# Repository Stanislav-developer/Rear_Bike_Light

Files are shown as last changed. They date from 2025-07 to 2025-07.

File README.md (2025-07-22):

# __Rear_Bike_Light__







## __DIY велоліхтарик__ 🚲 🔦
### Простий та функціональний задній ліхтарик для велосипеда на базі мікроконтролера ATtiny13. Ліхтарик має різні режими світіння, функцію пам’яті режимів та енергозбереження, стабілізацію яскравості і працює від Li-Ion акумулятора
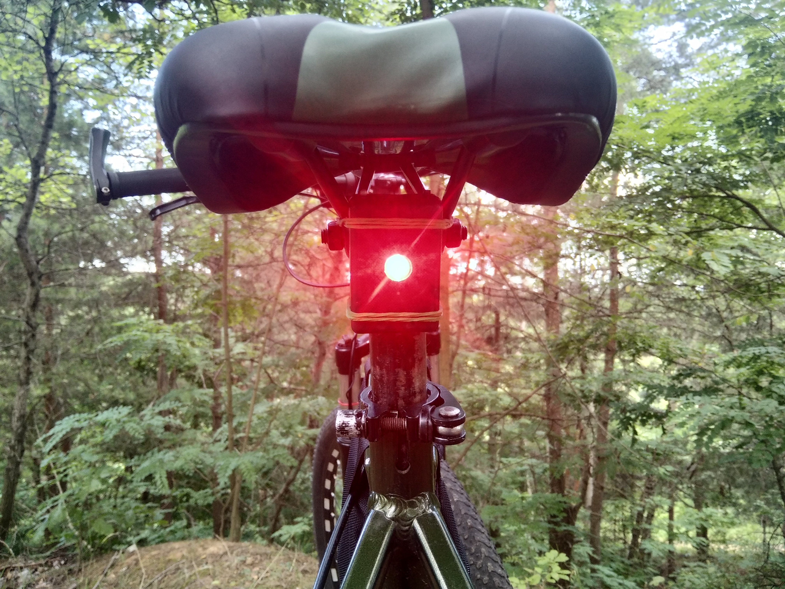
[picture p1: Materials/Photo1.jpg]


### 📹 [Відеодемонстрація роботи](https://youtu.be/wDcFlRhbskA)

### 📹 [Огляд на YouTube](https://youtu.be/hUzTWR3Yd6k?si=01EYvAU8pgUhFRcD)
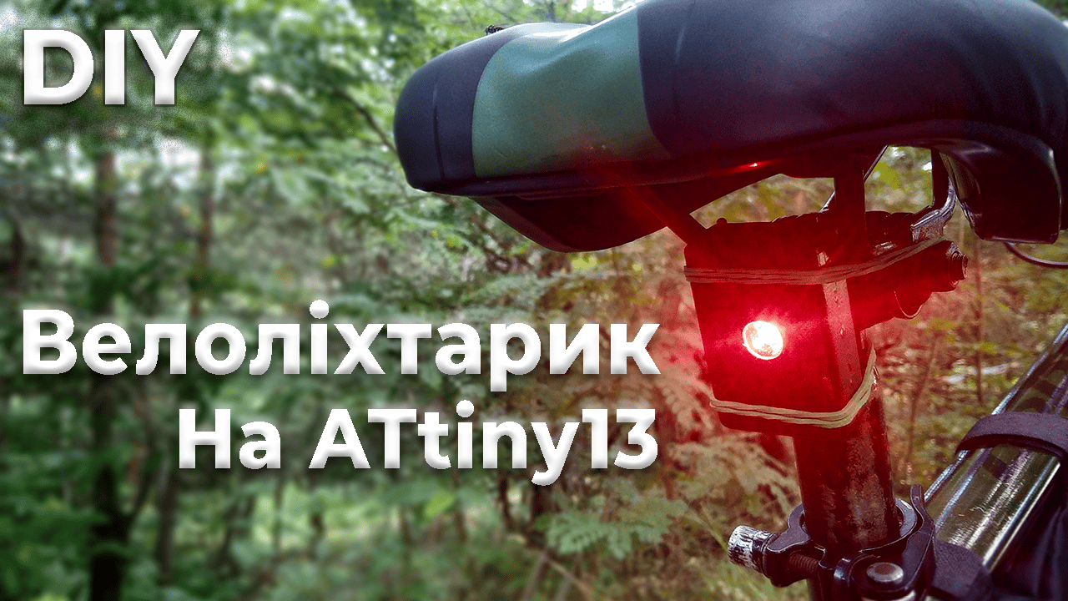
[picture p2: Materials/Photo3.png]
(https://youtu.be/hUzTWR3Yd6k)


## 📝 Можливості ліхтарика
- ### Керування однією кнопкою (довге/коротке натискання)
- ### Режими світіння: 3 рівня яскравості, миготіння, дихаючий режим, еко-режим
- ### Запам’ятовує останній режим (енергонезалежна EEPROM пам’ять)
- ### Стабілізована яскравість (AMC7135)
- ### Дуже низьке споживання енергії в режимі сну (~20 мкА)

## Схема ліхтарика:
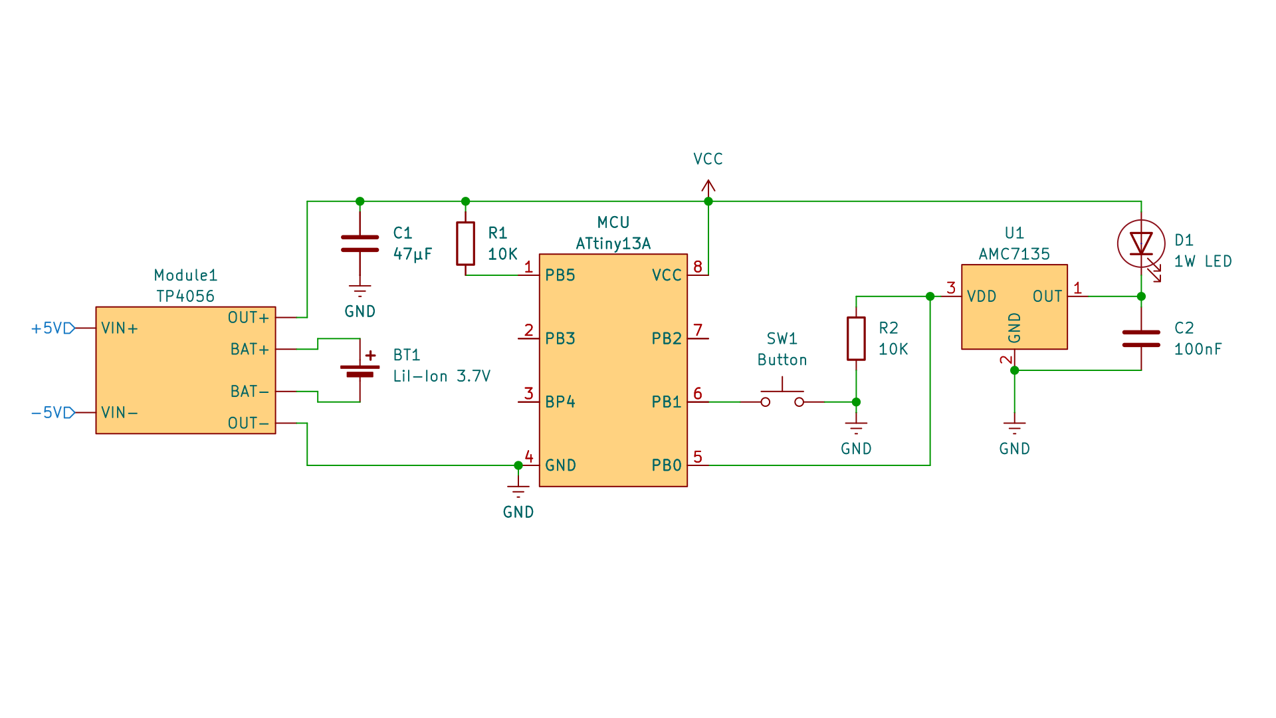
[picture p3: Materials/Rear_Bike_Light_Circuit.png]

### Перелік компонентів, інструкція з пайки та схема розміщені у [PDF документації](https://github.com/Stanislav-developer/Rear_Bike_Light/blob/main/Rear_Bike_Light.pdf)

## 📑 [PDF документ](https://github.com/Stanislav-developer/Rear_Bike_Light/blob/main/Rear_Bike_Light.pdf) у якому описав весь функціонал, збірку та прошивку ліхтарика.

### Поточна версія проекту: 1.0

### [Мій YouTube](https://www.youtube.com/@TehnoMaisterna)
### [Мій GitHub](https://github.com/Stanislav-developer)

### 2025.07.20

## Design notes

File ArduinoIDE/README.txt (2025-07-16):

Спершу встановіть ядро для роботи з ATtiny13:

Установка ядра MicroCore в Arduino IDE
Для роботи MicroCore потрібна версія Arduino IDE не нижче 1.6.13.
Інструкція з встановлення:

1.Відкрийте Arduino IDE.

2.Перейдіть у меню Файл → Налаштування.

3.У поле Додаткові URL-адреси менеджера плат вставте наступне посилання:

https://mcudude.github.io/MicroCore/package_MCUdude_MicroCore_index.json

4.Відкрийте меню Інструменти → Плата → Менеджер плат...

Дочекайтеся, поки завершиться завантаження індексів платформ.

5.Прокрутіть список вниз, знайдіть пункт MicroCore та натисніть на нього.

6.Натисніть кнопку Встановити.

7.Після завершення встановлення закрийте вікно менеджера плат.

Перед записом скетчу в мікроконтролер переконайтеся що у вас виставлені такі налаштування у вікні tools(інструменти):

Board(плата): ATtiny13 (MicroCore → ATtiny13)
BOD: BOD 2.7
EEPROM: EEPROM retained
Clock: 9.6 MHz

Programmer(програматор): USBasp або Arduino as ISP(Якщо ви прошиваєте через плату Arduino UNO,NANO)

Перед прошивкою рекомендується спершу записати Bootloader у мікроконтролер(для цього у самому низу натисніть Burn Bootloader (Записати завантажувач)

Тепер можна завантажити прошивку:
(Вікно Sketch → Upload Using Programmer)

Готово!

Якщо виникли проблеми, рекомендую глянути це відео:
https://youtu.be/dbkITW6Pz68?si=roI1-eetyj3U_qAi

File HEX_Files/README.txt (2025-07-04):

Щоб зашити HEX файл у мікроконтролер виконуємо:
1.Підключіть ATtiny через USBasp програматор до комп'ютера
2.Відкрийте SinaProg
3.У верхньому пінкті виберіть .hex файл який хочете завантажити
4.У пункті Device натисніть search і у вас має оприділитись ATtiny13
5.У пункті Flash натисніть Program, Прошивка повинна успішно завантажитись
6.У пункті Fuses натисніть Advanced та виставіть High Fuse: xFB Low Fuse: x3A решту пунктів залишіть по замовчуванню
7.Нижче натисніть Write, фюзи повинні успішно записатись

Готово!

Якщо виникли проблеми та мікроконтролер працює не так як потрібно то у вікні Advanced натисніть Chip Erase(Це повністю очистить прошивку мікроконтролера)
Після чого повторіть всі попередні дії

Повинно все вийти!

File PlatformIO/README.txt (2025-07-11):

Перед початком переконайтеся що у вас втановлено Visual Studio Code та PlatformIO актуальної версії.
Також переконайтеся щоб був встановлений драйвер на USBasp програматор.

1. Завантажте архів репозиторію за цим посиланням: https://github.com/Stanislav-developer/Rear_Bike_Light/archive/refs/heads/main.zip
2. Розпакуйте папку PlatformIO на робочий стіл або у інше зручне місце на комп'ютері.
3. У VS Code на лівій бічній панелі відкрийте розширення PlatformIO.
4. Натисніть Pick a folder та виберіть папку PlatformIO яку ви розпакували з архіву.
5. На лівій бічній панелі знову натисніть на іконку PlatformIO.
6. У меню QUICK ACCES → Miscellaneous виберіть: PlatformIO Core CLI (У вас повинен відкритися термінал PlatformIO).
7. Підключіть програматор USBasp з мікроконтролером до комп'ютеру.
8. Тепер переходимо до запису ф'юзів та прошивки в ATtiny13:
   -----------------------------------------------------------------
   Щоб завантажити 1 варіант прошивки у мікроконтролер, введіть такі команди:

   Записуємо ф'юзи:
   pio run -e firmware_1 -t fuses
   
   Записуємо прошивку:
   pio run -e firmware_1 -t upload

   -----------------------------------------------------------------
   Щоб завантажити 2 варіант прошивки у мікроконтролер, введіть такі команди:

   Записуємо ф'юзи:
   pio run -e firmware_2 -t fuses
   
   Записуємо прошивку:
   pio run -e firmware_2 -t upload

   -----------------------------------------------------------------
   Щоб завантажити 3 варіант прошивки у мікроконтролер, введіть такі команди:

   Записуємо ф'юзи:
   pio run -e firmware_3 -t fuses
   
   Записуємо прошивку:
   pio run -e firmware_3 -t upload

Під час запису фюзів та прошивки процес повинен завершуватись з статусом SUCCESS, якщо це не так то переконайтеся що мікроконтролер надійно підключений до програматора та встановлено відповідний драйвер.

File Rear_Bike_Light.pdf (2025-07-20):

# Rear Bike Light

Задній велоліхтарик

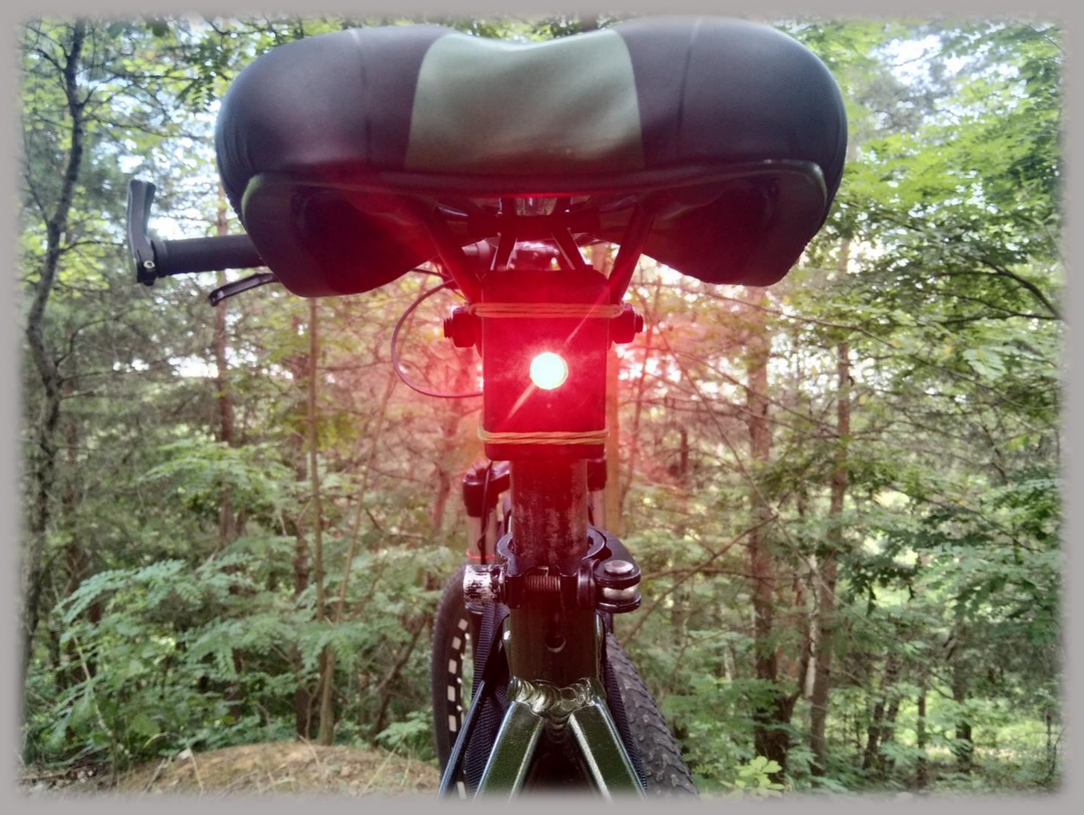
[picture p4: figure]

Зміст:

### 1. Вступ 2. Опис проекту 3. Схема ліхтарика 4. Код та прошивка 5. Збірка ліхтарика 6. Тести на вулиці 7. Висновок

Репозиторій проекту:
https://github.com/Stanislav-developer/Rear_Bike_Light Відео огляд:
https://youtu.be/hUzTWR3Yd6k
Автор проекту:
YouTube: https://www.youtube.com/@TehnoMaisterna GitHub: https://github.com/Stanislav-developer

## Вступ

У цьому документі я описав можливості ліхтарика та процес його створення, а також написав інструкції щодо прошивки мікроконтролера.

Задній ліхтарик на велосипед (назва проекту Rear_Bike_Light). Щоб безпечно їздити на велосипеді у темну пору доби, потрібно зробити себе видимим для інших учасників дорожнього руху, тому я вирішив зробити ліхтарик(блималку) для свого велосипеду. Не хотів купувати готові рішення десь у магазинах або на Алі, бо нормальні ліхтарі коштують немалих грошей, а ті що дешевші працюють тільки від батарейок, недовго тримають заряд та мають інші недоліки. Тому вирішив зробити такий ліхтарик самотужки під власні потреби.

У результаті у мене вийшов хороший задній велоліхтарик з багатьма режимами роботи, також його можна використовувати і як простий ліхтарик для повсякденного користування.

Всі матеріали для повторення ліхтарика я виклав на GitHub. (https://github.com/Stanislav-developer/Rear_Bike_Light)
Також зняв відеоогляд цього ліхтарика на YouTube (https://www.youtube.com/@TehnoMaisterna)

Хоча ліхтарик працює стабільно і весь функціонал мені вдалося зробити, але допускаю що проект ще не досконалий, адже можна краще оптимізувати прошивку, придумати якийсь корпус та кращий метод кріплення та можливо внести якісь зміни у схему.

Також є ідеї щоб додати датчик освітленості або вібрації щоб ліхтарик включався тільки за певних умов, але поки це тільки задум.

У будь-якому випадку все у відкритому доступі і ви самі за бажанням можете внести свої зміни.

Якщо у вас є будь-які пропозиції або ідеї щодо цього проекту:
Моя пошта: turiistanislav@gmail.com

## Опис

Задній ліхтарик блималка на велосипед. Робить велосипедиста видимим для інших учасників дорожнього руху. Ліхтарик побудований на компактному та дешевому мікроконтролері ATtiny13, для живлення використовується будь-який Li-ion або Li-po акумулятор номінальною напругою 3.7 вольт. Наявні різноманітні режими роботи, присутні: функція пам’яті, стабілізація яскравості, та енергозбереження. Керування:
Ліхтарик керується всього однією кнопкою та вміє розпізнавати довге та коротке натискання. Коротким натисканням ви вмикаєте та вимикаєте ліхтарик, довгим натисканням ви по черзі змінюєте режими роботи ліхтарика.
Функція пам’яті:
Після вимкнення ліхтарика він запам’ятовує вибраний вами режим та при наступному ввімкнені вмикає його, номер режиму зберігається у EEPROM пам'ять в мікроконтролері, тому якщо акумулятор розрядиться, ліхтарик всерівно буде пам’ятати останній вибраний режим.

Енергозбереження:
Коли ліхтарик вимкнений то мікроконтролер переходить у режим сну, споживання мікросхеми при цьому близько: 0,00002А (20мкА), щоб повністю розрядити акумулятор ємністю 1A/год потрібно близько 5 років.

Стабілізація яскравості:
Замість резистора у ліхтарику використовується маленька та дешева мікросхема led драйвер AMC7135 яка стабілізує струм на світлодіоді в 350мА. Яскравість червоного 1W світлодіоду залишається стабільною на всьому діапазоні напруги акумулятора (2,8 – 4,2 V). Також при бажанні ви можете поставити 1W світлодіод іншого кольору

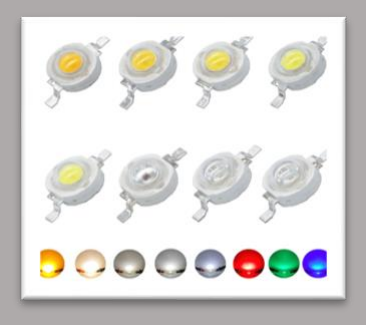
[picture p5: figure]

## Опис

Наразі написав для ліхтарика три варіанти прошивки з різними режимами роботи:

Прошивка 1:
1.Максимальна яскравість (Споживання: 350 мА) 2.Середня яскравість (Споживання: ~150 мА) 3.Мінімальна яскравість (Споживання: ~40 мА)
4.Режим миготіння повільний
5.Режим миготіння швидкий
6.Режим альтернативного миготіння повільний (Чергування слабкої та сильної яскравості)
7.Режим альтернативного миготіння швидкий (Чергування слабкої та сильної яскравості)
8.Еко режим (Спалахує кожні 1,5 секунди. Береже заряд акумулятору та добре помітний у день)

Прошивка 2:
1.Максимальна яскравість (Споживання: 350 мА) 2.Середня яскравість (Споживання: ~150 мА) 3.Мінімальна яскравість (Споживання: ~40 мА)
4.Режим миготіння повільний
5.Режим миготіння швидкий
6.Дихаючий режим або ж FADE (Плавне згасання та загорання світлодіода) 7.Еко режим (Спалахує кожні 1,5 секунди. Береже заряд акумулятору та добре помітний у день)

Прошивка 3:
1.Максимальна яскравість (Споживання: 350 мА)
2.Середня яскравість (Споживання: ~150 мА)
3.Мінімальна яскравість (Споживання: ~40 мА)

Відеодемонстрація роботи ліхтарика з різними прошивками: https://youtu.be/wDcFlRhbskA?si=2nNuUyQIVljCF-LK

Ви зможете завантажити одну з трьох прошивок на вибір, інструкція щодо цього буде у розділі “Код та прошивка”

## Опис

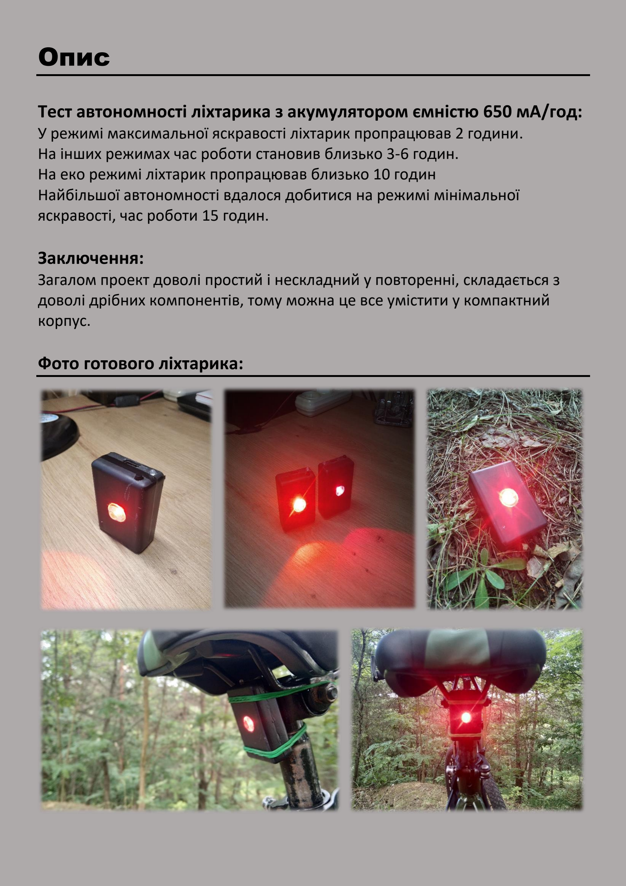
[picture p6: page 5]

Тест автономності ліхтарика з акумулятором ємністю 650 мА/год: У режимі максимальної яскравості ліхтарик пропрацював 2 години.
На інших режимах час роботи становив близько 3-6 годин.
На еко режимі ліхтарик пропрацював близько 10 годин
Найбільшої автономності вдалося добитися на режимі мінімальної яскравості, час роботи 15 годин.

Заключення:
Загалом проект доволі простий і нескладний у повторенні, складається з доволі дрібних компонентів, тому можна це все умістити у компактний корпус.

Фото готового ліхтарика:

## Схема

Схема ліхтарика:

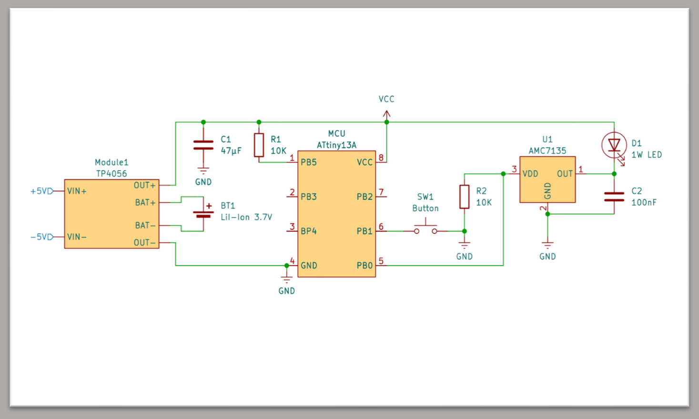
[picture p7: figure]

Файли KiCad та фото схеми у повній якості: https://github.com/Stanislav-developer/Rear_Bike_Light/tree/main/Materials

Що робить кожен компонент:

### 1. Module1 TP4056 (обов’язковий компонент):

Модуль заряду акумулятора, потрібно використовувати модуль з захистом від перерозряду, щоб не розрядити акумулятор нижче 2,5V

### 2. MCU ATtiny13 (обов’язковий компонент):

Мікроконтролер, який реалізує основний функціонал ліхтарика, а саме: обробляє натискання кнопки, генерує ШІМ сигнал, перемикає режими роботи, зберігає режим роботи у внутрішню енергонезалежну пам’ять та інші технічні функції.

### 3. U1 AMC7135 (обов’язковий компонент):

Лінійний стабілізатор струму для світлодіоду, стабілізує струм світлодіода на рівні 350мА. На контакт VDD подається ШІМ сигнал мікроконтролера, таким чином регулюється яскравість світлодіода.

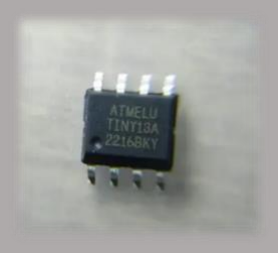
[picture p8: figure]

## Схема

### 4. D1 1W LED (обов’язковий компонент):

1 Ватний світлодіод будь-якого кольору, також може бути матриця або збірка світлодіодів розрахованих на струм 350 мА .

### 5. BT1 Li-Ion 3.7V (обов’язковий компонент):

Li-Ion 18650 або Li-po акумулятор з одноразки, підійде будь-який, головне щоб влазив у корпус. Рекомендована ємність: 300мА/год – 1А/год.

### 6. SW1 Button (обов’язковий компонент):

Тактова кнопка, використовуйте любу на ваш смак)

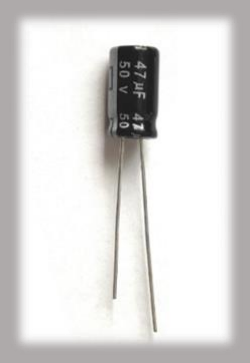
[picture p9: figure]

### 7. C1 47 µF (необов’язковий компонент):

Електролітичний конденсатор ємністю від 22мкФ до 100мкФ. Потрібен для фільтрації пульсацій струму та шумів на лінії живлення.
Обов’язково ставте якщо плануєте живити ліхтарик від імпульсних джерел живлення: AC-DC або DC-DC перетворювачі або різноманітні блоки живлення. Якщо ліхтарик плануєте живити від акумулятора то цей конденсатор необов’язковий, але краще поставити для стабільнішої роботи.

### 8. C1 100nF (необов’язковий компонент):

Керамічний конденсатор для стабільної роботи стабілізатора AMC7135.
Необов’язковий компонент, але бажано поставити для стабільнішої роботи.

### 9. Резистори R1 та R2 (необов’язкові компоненти):

R1 підтягує 1 пін мікроконтролера RESET до VCC, щоб не було спонтанних перезавантажень мікроконтролера.
R2 підтягує 5 пін мікроконтролера до GND, щоб стабілізатор точно був вимкненим коли мікроконтролер у режимі сну.
Резистори необов’язкові але все таки їх бажано поставити для стабільної роботи ліхтарика.

## Код та прошивка

Весь вихідний код прошивок міститься в основному каталозі репозиторію: https://github.com/Stanislav-developer/Rear_Bike_Light

Є три варіанти як ви можете прошити мікроконтролер:

1. За допомогою Arduino IDE. (https://www.arduino.cc/en/software/) Класичний метод, знайомий для багатьох.
2. За допомогою PlatformIO. (https://platformio.org/) Для когось це може бути зручніше.
3. За допомогою бінарного HEX файлу, для тих хто не хоче паритись.

Для прошивки використовую програматор USBasp:

Купити USBasp на алі (https://www.aliexpress.com/item/32582933115.html?sku_id=65126983393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)

Купити USBasp в україні (https://www.rcscomponents.kiev.ua/product/usbasp-prohramator-avr-v2-0-draiver-i-pz-na-saiti-rcscomponents-kiev-ua_46535.html)

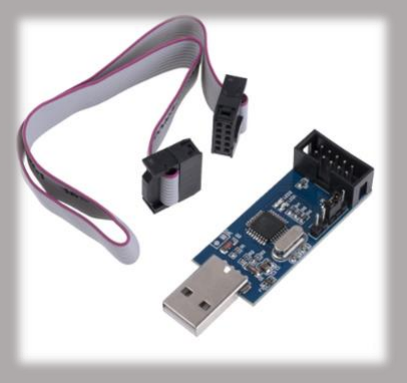
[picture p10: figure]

Переконайтеся що у вас встановлено драйвер для USBasp програматора: Завантажити драйвер (https://www.instructables.com/USBASP-Installation-in-Windows-10/)

Підключаємо ATtiny13 до програматора за наступною схемою:

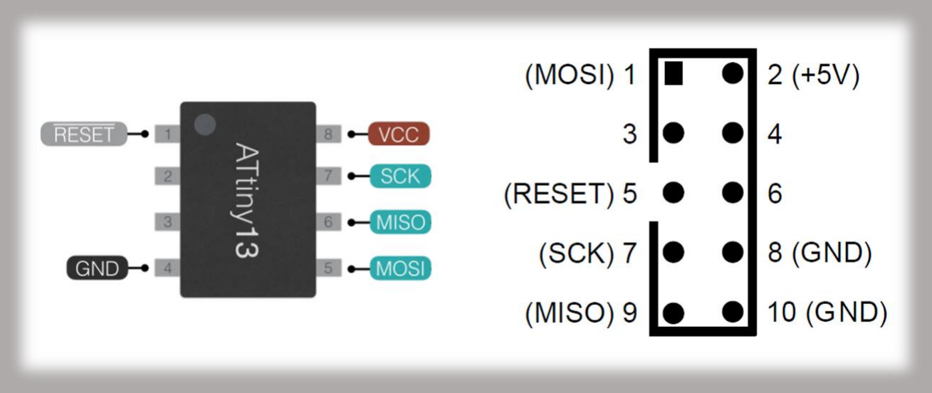
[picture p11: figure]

## Код та прошивка

Прошивка за допомогою ArduinoIDE:

1. Встановіть Arduino IDE (https://www.arduino.cc/en/software/) та відкрийте його.
2. Підключіть програматор з мікроконтролером до комп’ютера.
3. Завантажте архів репозиторію (https://github.com/Stanislav-developer/Rear_Bike_Light.git) та розпакуйте папку Arduino IDE з нього.
4. У папці знайдіть файл README.txt та відкрийте його.
5. Слідуйте інструкції з файлу README.txt.

Якщо виникнуть проблеми, раджу подивитись моє відео на цю тему: https://youtu.be/dbkITW6Pz68?si=xsdvo8xUebu8vKtH

Прошивка за допомогою PlatformIO:

1. Встановіть VS Code (https://code.visualstudio.com/) з офіційного сайту, та розширення PlatformIO (https://platformio.org/platformio-ide) до нього.
2. Слідуйте інструкції з README (https://github.com/Stanislav-developer/Rear_Bike_Light/blob/main/PlatformIO/README.txt) файлу в папці PlatformIO. (https://github.com/Stanislav-developer/Rear_Bike_Light/tree/main/PlatformIO)

Прошивка HEX файлу в мікроконтролер:

1. Завантажте архів репозиторію (https://github.com/Stanislav-developer/Rear_Bike_Light.git) та розпакуйте папку HEX_Files з нього.
2. У папці HEX_Files ви знайдете папку SinaProg, це програма(графічна оболонка до avrdude) для завантаження HEX файлу в мікроконтролер.
3. Також у папці буде README файл, слідуйте інструкції з нього…

Для комфортнішої прошивки мікроконтролерів в soic-8 корпусах, рекомендую замовити такий перехідник:

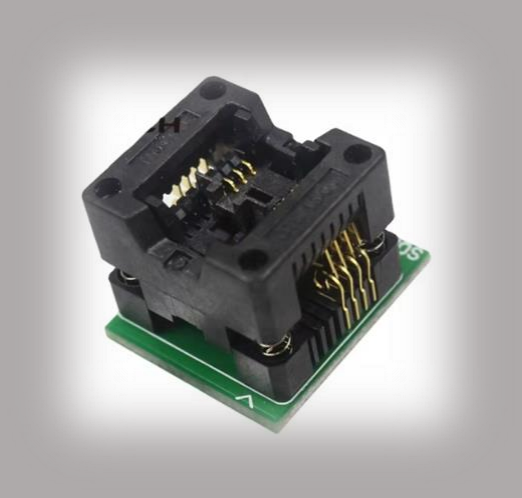
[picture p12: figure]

### Купити на Алі (https://www.aliexpress.com/item/1988128275.html?mp=1)

## Збірка

### Що нам знадобиться?

### 1.Компактний корпус

Брав тут: https://arduino.ua/ru/prod2708-miniaturnii-korpys-diplekser-dip

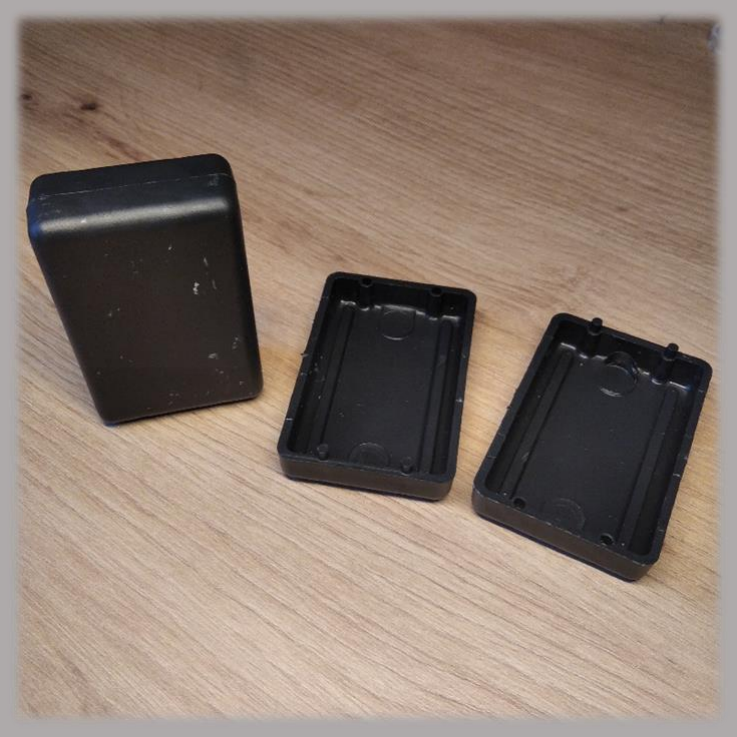
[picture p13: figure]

### 2.Літій-полімерний акумулятор на 650 ма/год витягнутий з одноразки

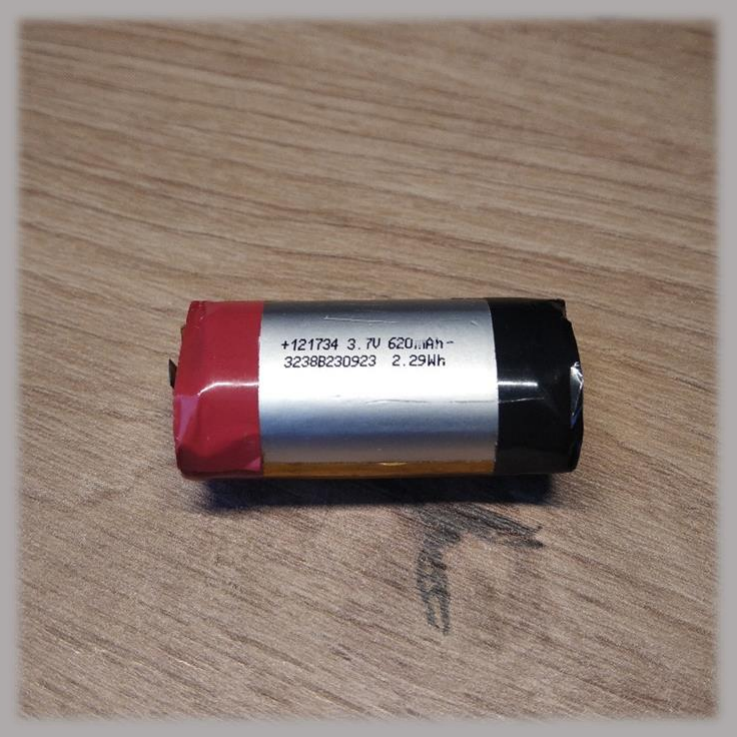
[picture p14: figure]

## Збірка

### 3.Плата заряду/розряду для Li-Ion акумуляторів TP4056

Брав тут:
https://www.aliexpress.com/item/1005005708489860.html?spm=a2g0o.order_list.order_list_main.56.2c8418024FGAM5 (https://www.aliexpress.com/item/1005005708489860.html)

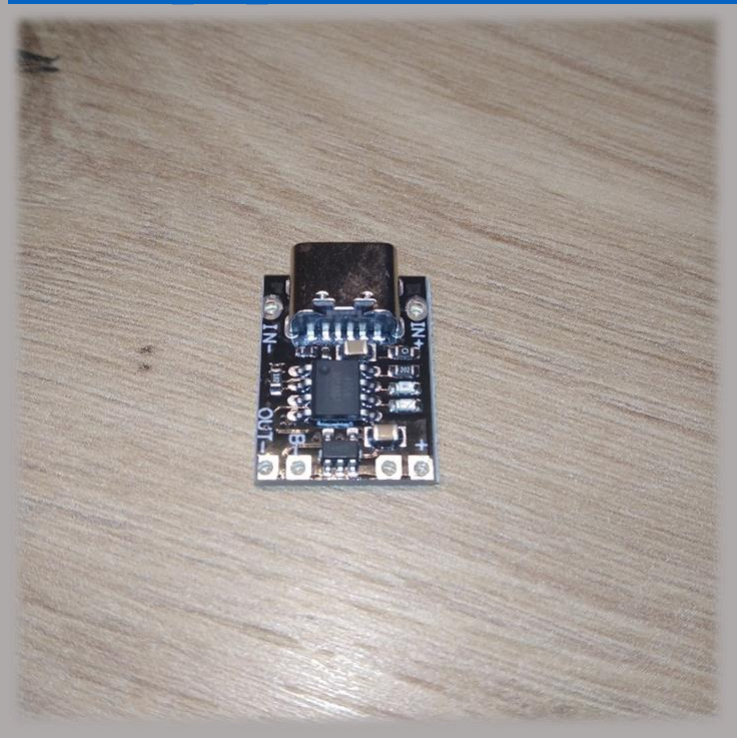
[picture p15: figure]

### 4.Червоний 1W світлодіод та лінза до нього

Купити світлодіод (https://www.aliexpress.com/item/1005008122904507.html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)
Купити лінзу, (https://www.aliexpress.com/item/32904718238.html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) лінзу краще беріть з якомога більшим кутом розсіяння 90 ° і більше.

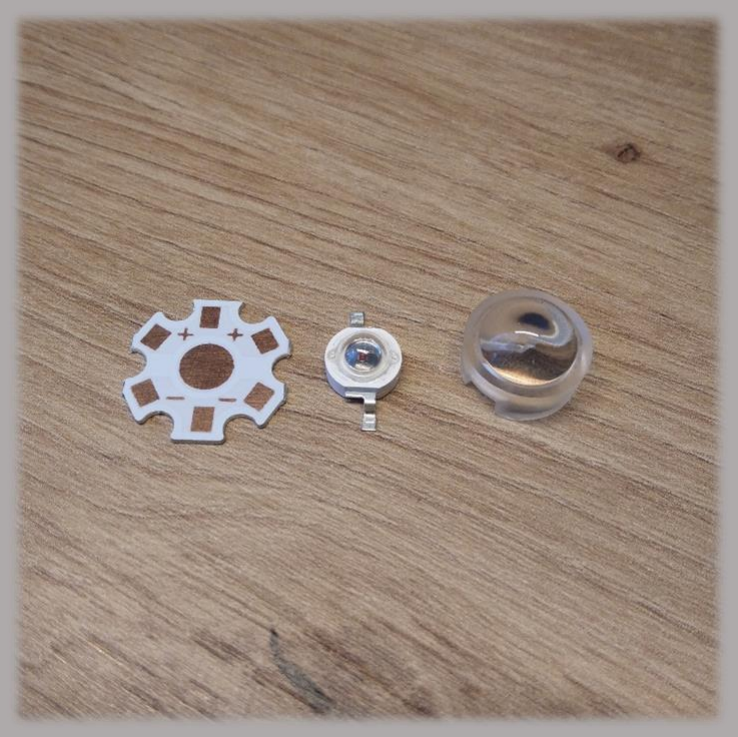
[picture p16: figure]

## Збірка

### 5. Мікроконтролер ATtiny13A з DIP адаптером

Мікроконтролер брав тут: https://www.mini-tech.com.ua/attiny13a-ssu Купити плату перехідник (https://www.aliexpress.com/item/32691027088.html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)

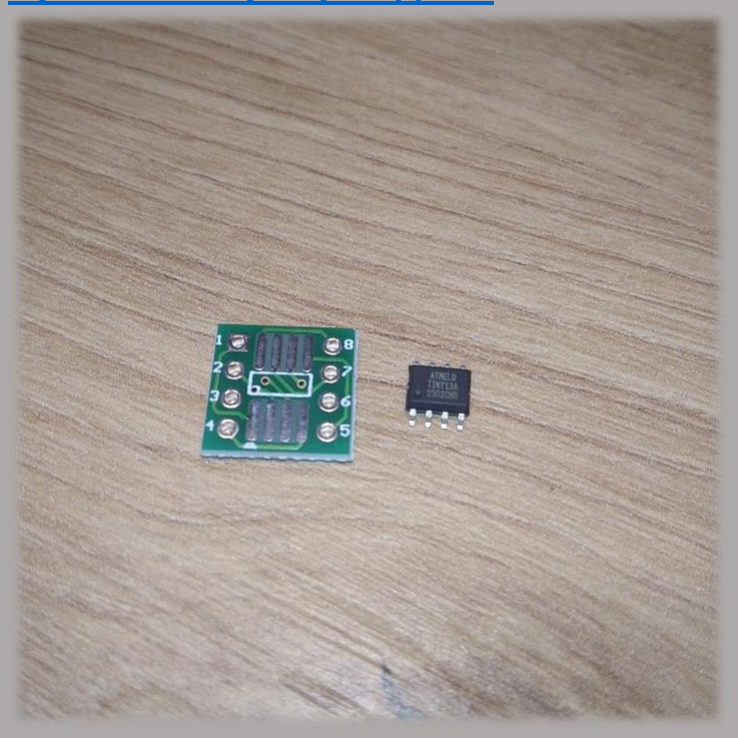
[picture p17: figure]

### 6. LED Драйвер, стабілізатор струму AMC7135:

Мікросхему брав тут: https://arduino.ua/ru/prod3942-svetodiodnii-draiver-amc7135-2-7-6v-350ma-sot-89 (https://arduino.ua/ru/prod3942-svetodiodnii-draiver-amc7135-2-7-6v-350ma-sot-89)
Плата перехідник: https://arduino.ua/ru/prod4078-plata-adapter-sip3-dlya-chipov-v-korpyse-sot89-i-sot223

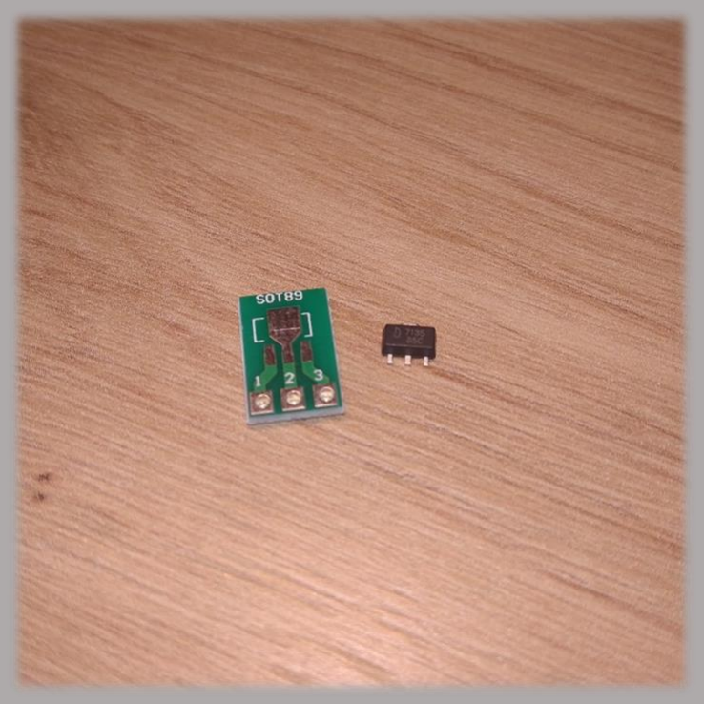
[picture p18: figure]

## Збірка

### 7. Решта деталей

Керамічний конденсатор на 100нФ Електролітичний конденсатор на 47мкФ 2 Резистори по 10кОм
1 Резистор на 3,3 кОм
Тактова кнопка
Це все можна купити у простому радіомагазині

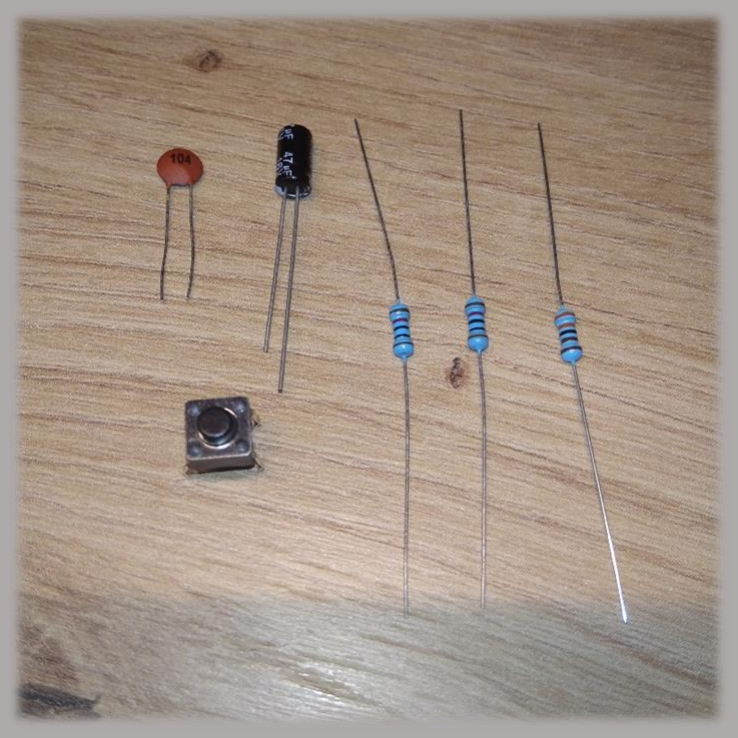
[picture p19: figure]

### Всі деталі разом:

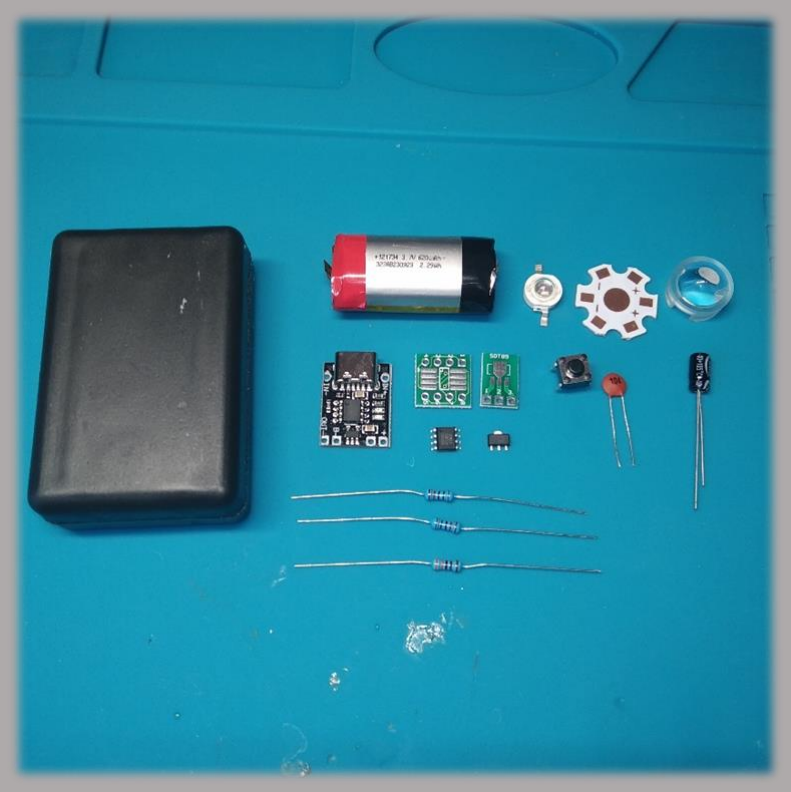
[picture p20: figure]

## Збірка

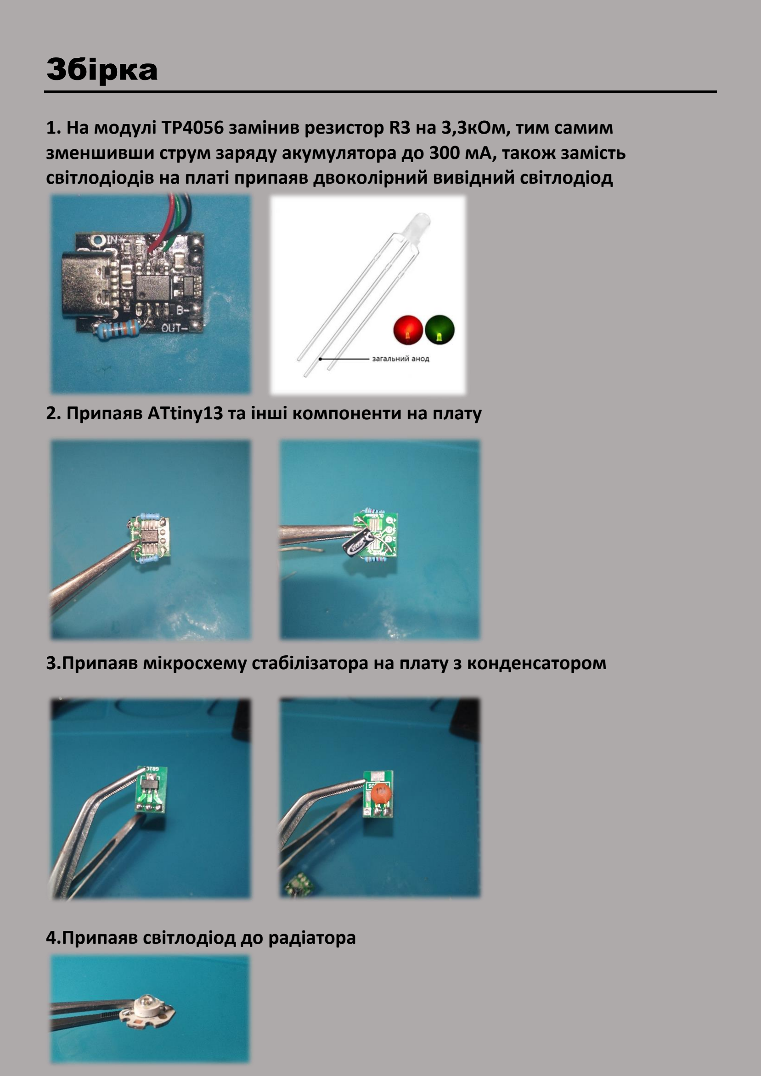
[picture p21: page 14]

### 1. На модулі TP4056 замінив резистор R3 на 3,3кОм, тим самим

зменшивши струм заряду акумулятора до 300 мА, також замість світлодіодів на платі припаяв двоколірний вивідний світлодіод

### 2. Припаяв ATtiny13 та інші компоненти на плату

3.Припаяв мікросхему стабілізатора на плату з конденсатором

4.Припаяв світлодіод до радіатора

## Збірка

5.Приклеїв TP4056 з кнопкою та світлодіодом індикації до корпусу

6.Припаяв ATtiny13 до кнопки та плати заряду

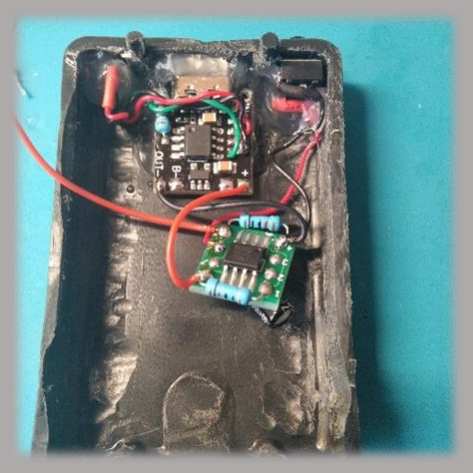
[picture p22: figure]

7.Припаяв до цього всього стабілізатор зі світлодіодом

8.Все проізолював та припаяв акумулятор

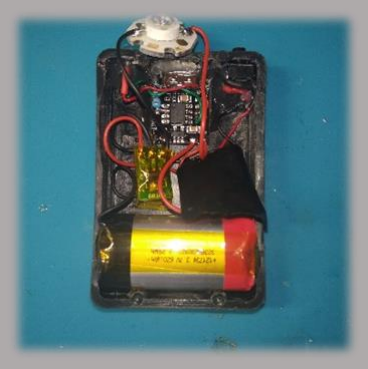
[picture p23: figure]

## Збірка

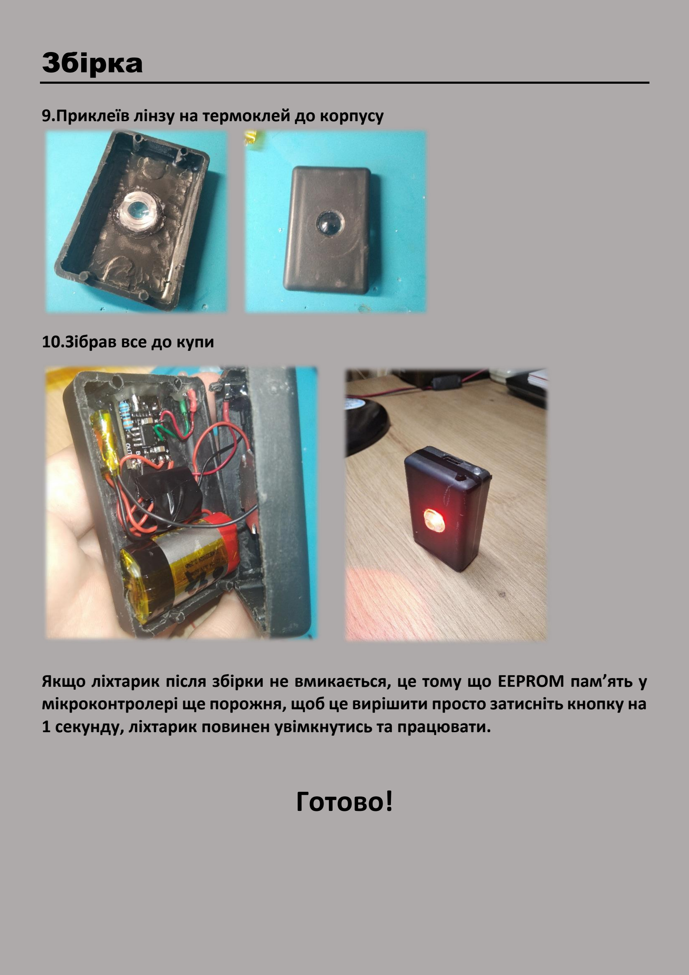
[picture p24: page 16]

9.Приклеїв лінзу на термоклей до корпусу

10.Зібрав все до купи

Якщо ліхтарик після збірки не вмикається, це тому що EEPROM пам’ять у мікроконтролері ще порожня, щоб це вирішити просто затисніть кнопку на 1 секунду, ліхтарик повинен увімкнутись та працювати.

## Готово!

## Тест на вулиці

Ліхтарик закріпив на велосипед за допомогою простих канцелярських резинок, дуже добре тримається. Також думаю на рахунок якогось кращого кріплення, можливо 3Д друк або можливо ви знаєте якісь готові рішення? Буду вдячний за будь які ідеї, пишіть на пошту: turiistanislav@gmail.com або коментарі під YouTube відео. (https://youtu.be/hUzTWR3Yd6k)

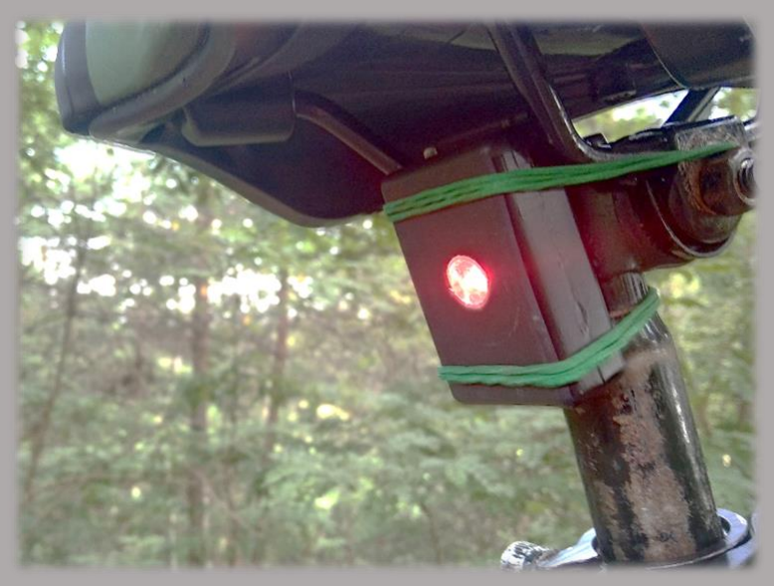
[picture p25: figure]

На вулиці ліхтарик показав себе непогано, навіть в день та сутінки він яскраво світить та досить помітний, у ніч він видався навіть занадто яскравим) Зазвичай їжджу на низьких режимах яскравості. Також його легко зняти з сідла та використовувати як простий ліхтарик.

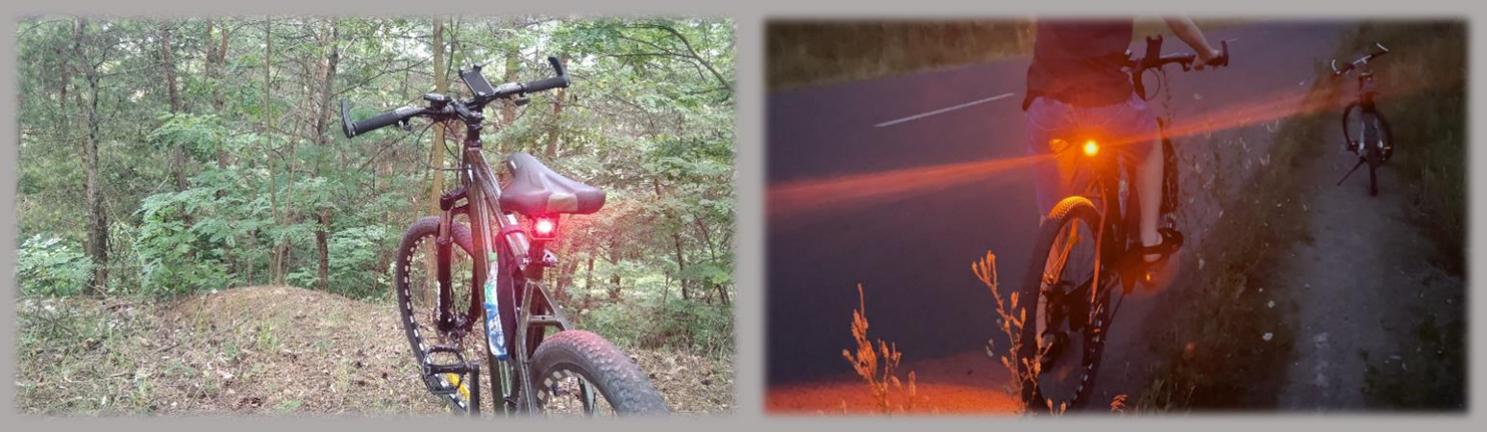
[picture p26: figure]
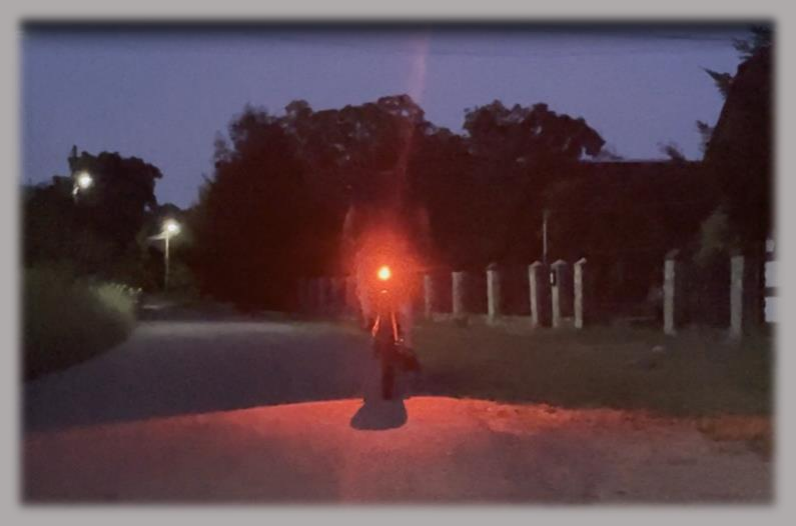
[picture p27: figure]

## Висновки

Мені було цікаво зробити такий ліхтарик, більше не як для використання, а було цікавіше саме розробляти його, придумати схему, написати код для мікроконтролера, спаяти це все та умістити в компактний корпус. Так як я новачок у програмуванні мікроконтролерів то умістити весь потрібний функціонал у ATtiny13 з 1КБ пам’яті було важкувато, але все таки вийшло, і не прийшлось робити проект на ATtiny85 або іншому мікроконтролері які будуть набагато дорожчими за ATtiny13. Як ідеї на майбутнє можна добавити:
1. Вібродатчик або датчик освітленості щоб ліхтарик включався тільки за певних умов.
2. Краще оптимізувати код та умістити всі режими в одну прошивку.
3. Додати поворотники і вивести необхідні кнопки на руль велосипеду.

Якщо у вас є якісь питання щодо проекту або пропозиції, пишіть на мою
пошту: turiistanislav@gmail.com

### Дякую за увагу!

Корисні посилання:

ATtiny13 datasheet (https://www.alldatasheet.com/datasheet-pdf/view/80274/ATMEL/ATTINY13.html)
AMC7135 datasheet (https://www.alldatasheet.com/datasheet-pdf/view/202788/ADDTEK/AMC7135.html)
ArduinoIDE (https://www.arduino.cc/en/software/)
PlatformIO (https://platformio.org/platformio-ide)
ATtiny13 MicroCore (https://mcudude.github.io/MicroCore/package_MCUdude_MicroCore_index.json)
USBasp driver (https://www.instructables.com/USBASP-Installation-in-Windows-10/)
Як запрограмувати ATtiny13/85 (https://youtu.be/dbkITW6Pz68?si=AmEbsb-b-f9ksqDt)
Зручний перехідник для прошивки мікроконтролерів ATtiny13/85 (https://youtu.be/O2dKDC8eGfw?si=IZul28RKjatBXHf4) Репозиторій проекту (https://github.com/Stanislav-developer/Rear_Bike_Light/tree/main/PlatformIO)
Відеоогляд ліхтарика (https://youtu.be/hUzTWR3Yd6k)
Огляд режимів роботи (https://youtu.be/wDcFlRhbskA?si=2nNuUyQIVljCF-LK)
Схема ліхтарика (https://github.com/Stanislav-developer/Rear_Bike_Light/blob/main/Materials/Rear_Bike_Light_Circuit.png)
Youtube канал (https://www.youtube.com/@TehnoMaisterna)
GitHub сторінка (https://github.com/Stanislav-developer)
Звязатися з автором

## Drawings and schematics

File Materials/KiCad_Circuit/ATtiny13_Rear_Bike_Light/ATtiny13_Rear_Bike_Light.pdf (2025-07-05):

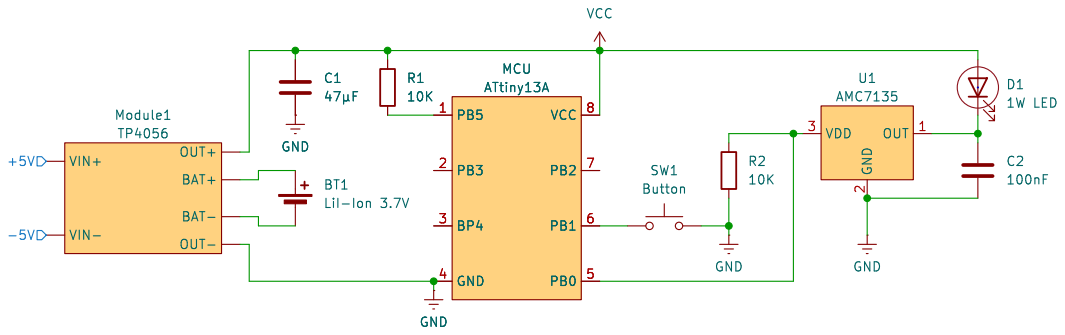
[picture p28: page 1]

Id: 1/1 Title: ATtiny13_Rear_Bike_Light_Circuit File: ATtiny13_Rear_Bike_Light.kicad_sch Sheet: /

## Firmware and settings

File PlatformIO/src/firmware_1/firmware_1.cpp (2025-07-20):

/*
Rear Bike Light - Firmware_1(Default)

* Author: Stanislav (GitHub: https://github.com/Stanislav-developer || Youtube: https://www.youtube.com/@TehnoMaisterna)
* Репозиторій проекту: https://github.com/Stanislav-developer/Rear_Bike_Light
* Date: 01-06-2025
* Ліцензія: MIT License – проєкт відкритий, вільно використовуй з зазначенням автора 

* Version: V1.0
  Функціонал:
  * Статичне світло з регулюванням яскравості в 3 ступені
  * Режими миготіння: повільний, швидкий, еко режим
  * Альтернативне миготіння (повільне та швидке)

* Опис:

  Прошивка заднього велоліхтарика, призначена для мікроконтролера ATtiny13/ATtiny13A

  Реалізує такий функціонал:

    1.Вкл/викл ліхтарик коротким нажаттям на кнопку

    2.Обробка довгого та короткого нажаття на кнопку та фільтрація дребезгу контактів

    3.Довге нажаття на кнопку(>1сек) включає наступний режим зі списку:
      1.Максимальна яскравість (Споживання: 350 мА)
      2.Середня яскравість (Споживання: ~150 мА)
      3.Мінімальна яскравість (Споживання: ~40 мА)
      4.Режим миготіння повільний
      5.Режим миготіння швидкий
      6.Режим альтернативного миготіння повільний (Чергування слабкої та сильної яскравості)
      7.Режим альтернативного миготіння швидкий (Чергування слабкої та сильної яскравості)
      8.Еко режим (Спалахує кожні 1,5 секунди. Береже заряд акумулятору та добре помітний у день)

    4.Збереження останнього вибраного режиму у енергонезалежну EEPROM память
      Вам не доведеться постійно перемикати всі режими щоб включити якийсь конкретний.
      Після виключення ліхтарика останній вибраний режим зберігається у енергонезалежну EEPROM память та при наступному включенні ліхтарика активується останній вибраний вами режим

    5.Реалізована функція SleepMode:
      Коли ліхтарик виключений, ATtiny13 активує переривання на піні INT0 та переходить у режим сну (SLEEP_PWR_DOWN).
      Споживання у режимі сну близько 0,00003 А тобто 30 мікроАмпер що дуже мало! Потрібно близько 4 років щоб повністю розрядити акумулятор 1Ah при такому режимі)

* Конфігурація пінів:
  5 пін(PB0) - керуючий вихідний pwm
  6 пін(PB1) - вхід для тактової кнопки з підтяжкою до VCC та перериванням INT0

*/

// ПІДКЛЮЧЕННЯ БІБЛІОТЕК
#include <Arduino.h> // Підключаємо бібліотеку Ардуїнівських функцій
#include <avr/sleep.h> // Підключаємо бібліотеку для роботи з sleep_mode

// ПРИВЯЗКА ПІНІВ
#define butPin 1 // 6 Пін кнопки (PB1)
#define ledPin 0 // 5 Пін виходу pwm (PB0)

// ОГОЛОШЕННЯ ЗМІННИХ

//Обробка кнопки:
#define debounceInterval 50 // Інтервал для фільтрації дребезгу контактів кнопки. За потреби (наприклад, при неякісній кнопці) збільшіть значення
#define buttonLongPressDuration 1000 // Час, після якого програма сприймає натискання кнопки як довге
bool previousStateButton = LOW; // Попередній стан кнопки (По дефолту не натиснута)
bool longPressState = false; // Стан довгого натиску (По дефолту FALSE)
unsigned long buttonLastPress; // Запамятовує момент коли кнопку натиснули(Час останнього натискання кнопки)
unsigned long previousButtonMillis; // Запамятовує час останнього зчитування стану кнопки з урахуванням debounceInterval
unsigned long buttonPressDuration; // Зберігає данні про те скільки часу кнопка утримується

// LightMode
byte lightMode = 8; // Зберігає номер поточного режиму світіння (По дефолту це 8 режим, світлодіод не світить)
#define EEPROM_ADDR 0 // Оголошуємо адрес eeprom памяті куди зберігатиметься змінна lightMode

// sleep_mode
volatile bool sleepState = true; // Показує чи перебуває мікроконтролер у режимі сну, якщо true - спить, якщо false - працює
volatile bool isFirstPress = false; // Показує чи було вже перше коротке або довге натискання перед сном, ця змінна потрібна для коректної обробки кнопки після виходу мікроконтролера з режиму сну

// Параметри для функції ledBlink
uint16_t onDuration; // Час увімкненого стану світлодіода
uint16_t offDuration; // Час вимкненого стану світлодіода
byte highBrightness; // Яскравість світлодіода в увімкненому стані
byte lowBrightness; // Яскравість світлодіода у вимкнутому стані

// ОСНОВНИЙ БЛОК КОДУ

void setup() {
  pinMode(butPin, INPUT_PULLUP); // Оголошуємо butPin як вхід з підтяжкою до VCC !Сигнал з кнопки інвертований
  pinMode(ledPin, OUTPUT); 

  MCUCR|= 1<<SE; // Вмикаємо можливість переходу в режим сну, те саме що sleep_enable()
  MCUCR|=(1<<SM1) | (0<<SM0); // Задаємо режим сну: "SLEEP_MODE_PWR_DOWN" самий економний режим сну (споживання ~30мкА)
  
  GIMSK|= 1<<INT0; // Вмикаємо переривання INT0 на 6 піні(PB1), переривання спрацьовує коли на піні зявляється LOW (низький рівень сигналу)
  sei(); // Дозволяємо глобальні переривання, насправді це не обовязково писати, але йой най буде)
}

// Функція читання з EEPROM
uint8_t eeprom_read(uint8_t addr) {
  while (EECR & (1 << EEPE));     // Чекаємо завершення попереднього запису
  EEAR = addr;                    // Записуємо адресу у регістр адреси EEPROM
  EECR |= (1 << EERE);            // Запускаємо операцію читання з EEPROM
  return EEDR;                    // Повертаємо прочитане значення з регістру даних EEPROM
}

// Функція запису в EEPROM
void eeprom_write(uint8_t addr, uint8_t data) {
  while (EECR & (1 << EEPE));     // Чекаємо, поки завершиться попередній запис
  EEAR = addr;                    // Встановлюємо адресу EEPROM, куди будемо записувати
  EEDR = data;                    // Записуємо байт даних у регістр даних EEPROM
  EECR |= (1 << EEMPE);           // Встановлюємо дозвіл на запис
  EECR |= (1 << EEPE);            // Виконуємо запис
}

// Функція мигання світлодіодом
void ledBlink(){
  static unsigned long previousMillis = 0; // Попередній час
  static bool ledState = false; // Стан світлодіоду
  
  // Якщо ledState is true та пройшло більше мілісекунд за onDuration
  if (ledState && millis() - previousMillis >= onDuration)
  {
    previousMillis = millis(); // Попередній час = поточний час
    ledState = false;
    analogWrite(ledPin, lowBrightness); //Включаємо світлодіод на яскравості lowBrightness
  }
  // Інакше якщо !ledState is true та пройшло більше мілісекунд за offDuration
  else if (!ledState && millis() - previousMillis >= offDuration)
  {
    previousMillis = millis(); // Попередній час = поточний час
    ledState = true;
    analogWrite(ledPin, highBrightness); //Включаємо світлодіод на яскравості highBrightness
  }
}

// Функція обробника кнопки
void buttonProcessing() {
  
  if(millis() - previousButtonMillis > debounceInterval) // Фльтруємо дребезг кнопки
  {
    bool buttonState = !digitalRead(butPin); // Читаємо стан кнопки та інвертуємо його, оскільки кнопка з INPUT_PULLUP  

    if (buttonState == HIGH && previousStateButton == LOW && !longPressState) // Перевіряє чи кнопка натиснута
    {
      buttonLastPress = millis();
      previousStateButton = HIGH;
    }

    buttonPressDuration = millis() - buttonLastPress; // Віднімаємо поточний час millis() від buttonLastPress щоб дізнатися скільки часу кнопка натиснута  

    if (buttonState == HIGH && !longPressState && buttonPressDuration >= buttonLongPressDuration) // Обробка довгого натискання
    {
      longPressState = true;
      lightMode = (lightMode + 1) % 8; // Поступово збільшуємо lightMode, якщо lightMode > 7 ми його обнуляємо
      // 8 це номер останнього режиму який по дефолту повинен вимикати світлодіод, тому якщо ви змінили кількість режимів то також змініть це значення

      if(!isFirstPress) //Перевірка чи ще не було короткого натискання кнопки після sleep_mode
      {
        isFirstPress = true;
      }
    }
      
    if (buttonState == LOW && previousStateButton == HIGH) // Перевіряє чи кнопка відпущена
    {
      previousStateButton = LOW;
      longPressState = false;
      
      if (buttonPressDuration < buttonLongPressDuration) // Обробка короткого натискання
      {

        if (isFirstPress) // Якщо коротке натискання вже відбулося після виходу зі сну
        {
          eeprom_write(EEPROM_ADDR, lightMode); // Записуємо останній вибраний режим у EEPROM
          lightMode = 8; // lightMode присвоюємо 8, це останній режим у якому світлодіод повинен бути повністю вимкненим
          sleepState = true; // Прапорець sleepState присвоюємо true, щоб мікроконтролер зайшов у сон
        }
        else
        {
          isFirstPress = true; 
        }
      }
    }
    previousButtonMillis = millis(); // Попередній час = поточний час
  }
}

// Функція перемикання режимів
void lightSwitch(){

  switch (lightMode) 
  {
    // 1 Режим (Максимальна яскравість)
    case 0:
    digitalWrite(ledPin, HIGH); // Cвітимо на максимальну яскравість (Споживання ~350мА)
    break;

    // 2 Режим (Середня яскравість)
    case 1:
    analogWrite(ledPin, 100); // Яскравість: 100 із 255, середня яскравість (Споживання ~140мА)
    break;

    // 3 Режим (Мінімальна яскравість)
    case 2:
    analogWrite(ledPin, 25); // Яскравість 25 із 255, мінімальна яскравість (Споживання ~40мА)
    break;

    // 4 Режим (Блимання повільне)
    case 3:
    // Задаємо значення перед викликом функції
    onDuration = 350;     // Світлодіод світить 350 ms
    highBrightness = 150; // Яскравість світлодіоду 150 із 255, яскравість трохи вище середньої
    offDuration = 350;    // Світлодіод виключений 350 ms
    lowBrightness = 0;    // Яскравість світлодіоду 0 із 255, виключений
    ledBlink();           // Викликаємо функцію
    break;

    // 5 Режим (Блимання швидке)
    case 4:
    // Задаємо значення перед викликом функції
    onDuration = 120;     // Світлодіод світить 120 ms
    highBrightness = 100; // Яскравість світлодіоду 100 із 255, середня яскравість
    offDuration = 120;    // Світлодіод виключений 120 ms
    lowBrightness = 0;    // Яскравість світлодіоду 0 із 255, виключений
    ledBlink();           // Викликаємо функцію
    break;

    // 6 Режим (Повільне альтернативне блимання)
    case 5:
    // Задаємо значення перед викликом функції
    onDuration = 600;     // Світлодіод світить 600 ms
    highBrightness = 255; // Яскравість світлодіоду 255 із 255, максимальна яскравість
    offDuration = 800;    // Світлодіод світить на нижчій яскравості 800 ms
    lowBrightness = 80;   // Яскравість світлодіоду 80 із 255, яскравість нижча середньої
    ledBlink();           // Викликаємо функцію
    break;

    // 7 Режим (Швидке альтернативне блимання)
    case 6:
    // Задаємо значення перед викликом функції
    onDuration = 350;     // Світлодіод світить 350 ms
    highBrightness = 255; // Яскравість світлодіоду 255 із 255, максимальна яскравість
    offDuration = 250;    // Світлодіод світить на нижчій яскравості 250 ms
    lowBrightness = 100;  // Яскравість світлодіоду 100 із 255, середня яскравість
    ledBlink();           // Викликаємо функцію
    break;

    // 8 Режим (Еко режим, тільки короткочасні імпульси)
    case 7:
    // Задаємо значення перед викликом функції
    onDuration = 60;      // Світлодіод світить 60 ms
    highBrightness = 255; // Яскравість світлодіоду 255 із 255, максимальна яскравість
    offDuration = 1500;   // Світлодіод виключений 1500 ms
    lowBrightness = 0;    // Яскравість світлодіоду 0 із 255, виключений
    ledBlink();           // Викликаємо функцію
    break;

    // Стан світлодіоду по замовчуванню (Виключений)
    case 8:
    analogWrite(ledPin, 0); // Яскравість 0 із 255, світлодіод виключений
    break;
  }
}

// Обробник переривань, запускається коли мікроконтролер знаходиться у режимі сну та спрацьовує переривання INT0 на PB1
ISR(INT0_vect){
  lightMode = eeprom_read(EEPROM_ADDR); // Читаємо останній режим світіння з EEPROM та присвоюєм його lightMode
  isFirstPress = false; // За замовчуванням, першого натиску на кнопку ще не було
  sleepState = false; // Прапорець sleepState виставляємо в false, тим самим забороняємо режим сну та виходимо з нього у функції sleepCheck
}

// Функція перевірки сну
void sleepCheck(){
  if(sleepState) // Якщо sleepState = true, тобто режим сну дозволено
  {
    MCUCR|= 1<<SE; // Вмикаємо можливість переходу в режим сну, те саме що sleep_enable()
    GIMSK|= 1<<INT0; // Вмикаємо переривання INT0 на 6 піні(PB1), переривання спрацьовує коли на піні зявляється LOW (низький рівень сигналу)
    sleep_mode(); // Солодко засинаємо :)
  }
  else
  {
    MCUCR&= ~(1<<SE); // Забороняємо перехід в режим сну, те саме що sleep_disable()
    GIMSK&= ~(1<<INT0); // Вимикаємо переривання INT0 на PB1
  }
}

// Головний цикл
void loop() {
  sleepCheck(); // Викликаємо функцію перевірки сну
  buttonProcessing(); // Викликаємо функцію обробника кнопки
  lightSwitch(); // Викликаємо функцію перемикання режимів світіння
}

// Версія прошивки: V1.0
// Усі режими стабільні, збереження в EEPROM працює
// Режим сну перевірено — 30μA в sleep_mode

// Код протестовано на ATtiny13A @9.6 MHz, BOD level - 2.7V, живлення 3.7В Li-ion (Fuses: lfuse: 3A hfuse: FB)

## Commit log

2025-07-04 Arduino Sketches
2025-07-05 KiCad files
    [ATtiny13_Rear_Bike_Light.kicad_pcb, ATtiny13_Rear_Bike_Light.kicad_sch]
2025-07-16 Add KiCad files
    [ATtiny13_Rear_Bike_Light.kicad_pcb, ATtiny13_Rear_Bike_Light.kicad_sch]
2025-07-17 Rename Ліхтарик з Одноразки Превю.png to Photo5.png
2025-07-20 Add new photo to materials
2025-07-26 Add folder with alternative firmware
    [7zDP_LZMA.cfg]
